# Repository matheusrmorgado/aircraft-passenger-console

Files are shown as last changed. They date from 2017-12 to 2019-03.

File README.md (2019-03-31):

# Controles Acessíveis em Aeronaves

## Projeto

Projeto desenvolvido em parceria com o [InovaLab@Poli](https://www.facebook.com/INOVALAB.POLI) e o [Centro Interdisciplinar de Tecnologias Interativas (CITI-USP)](http://www.lsi.usp.br/citi/).

O relatório completo do trabalho está disponível em [final-report.pdf](https://github.com/matheusrmorgado/aircraft-passenger-console/blob/master/final-report.pdf).

Uma apresentação resumida do projeto e dos resultados está disponível em [poster-presentation.pdf](https://github.com/matheusrmorgado/aircraft-passenger-console/blob/master/poster-presentation.pdf).

<p align="center">
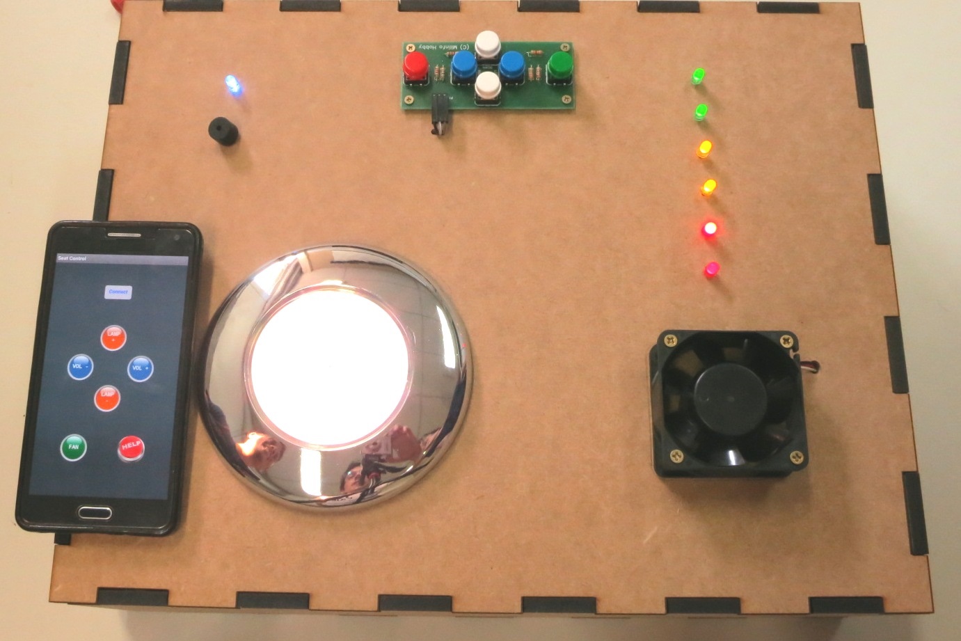
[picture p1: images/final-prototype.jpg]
  
</p>
<p align="center">
  <i> Youtube Video - https://youtu.be/7tW5oUx-QU8</i>
</p>

## Apresentação em Eventos

### Campus Mobile 2016 (Air Assistant)

> https://www.institutonetclaroembratel.org.br/educacao/nossas-novidades/noticias/jovens-empreendedores-se-reunem-na-etapa-presencial-do-programa-campus-mobile/

### IEEE ISCE 2016 (Enabling Technologies)

> http://isce2016.org.br/#overview_and_technical_program 

### TOM 2016  (Projetos 2016 - Slide 29)

> http://tom-sp.sedpcd.sp.gov.br/img/TOM.pdf

## Participação em Reportagens

### Movimento Maker - Estadão

> http://infograficos.estadao.com.br/e/focas/movimento-maker/tem-maker-na-medicina.php

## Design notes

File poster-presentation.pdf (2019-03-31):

# Accessible aircraft seat and console controls for passengers with disabilities through mobile devices

Matheus R. MORGADO, Marcelo A. JOSÉ, Member, IEEE, Alexandre M. ROCHA, André L. FLEURY,

Roseli D. LOPES, Member, IEEE, Eduardo S. ZANCUL Escola Politécnica
Universidade de São Paulo, São Paulo, Brazil matheus.morgado@usp.br, marcelo.archanjo@usp.br, arocha@usp.br, alfleury@usp.br, roseli.lopes@usp.br, ezancul@usp.br

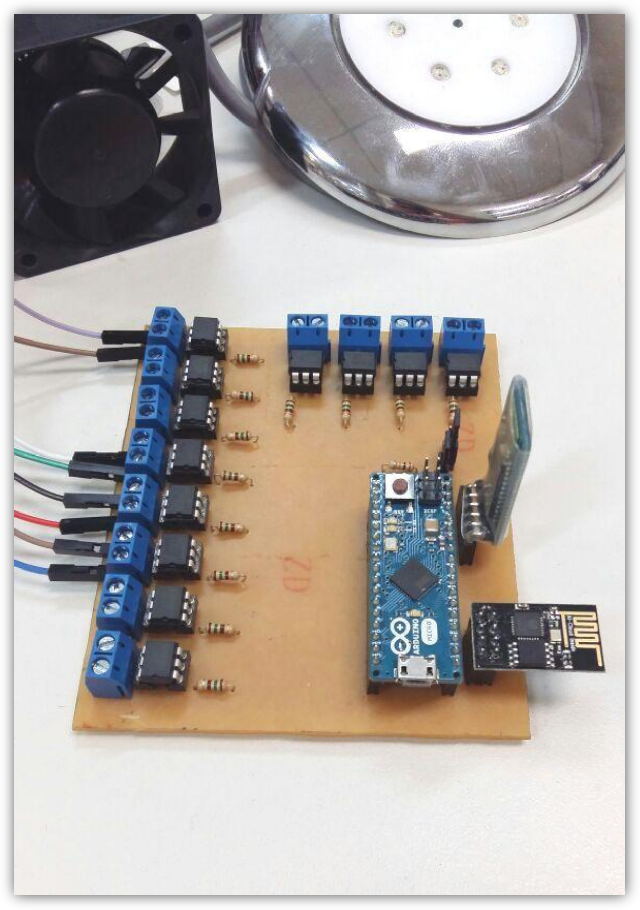
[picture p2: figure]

II. METHODS

This project is part of a larger project focused in the development of assistive technologies for improving the flight experience for people with disabilities or reduced mobility.

The project follows a methodological approach based on design thinking. The design thinking approach includes an initial project stage focused in the user understanding, followed by successive ideation and prototyping cycles.

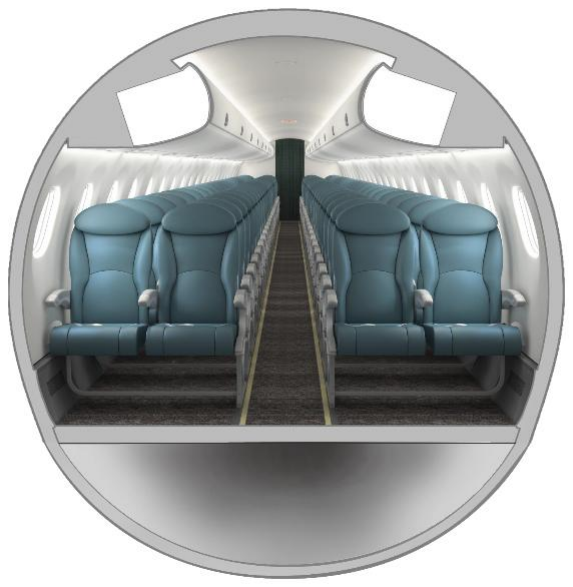
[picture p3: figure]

III. DEVELOPMENT

I. INTRODUCTION

People with disabilities usually face difficulties during travel in aircrafts. Among these difficulties, there are limitations while seated during the journey. The seat and console controls may be hard to reach and use or not accessible at all.

Considering the trend of airliners to allow the usage of wireless devices during flights, personal mobile devices become an option for improving comfort and creating a better experience for passengers with disabilities.

IV. RESULTS

The switches of the IFE controls, reading light and flight attendant call button of the aircraft represented in the final prototype were placed in parallel with solid state relays controlled by the Arduino.

The Arduino connects to a mobile device using Bluetooth or Wi-Fi and is controlled by a mobile application developed for this purpose.

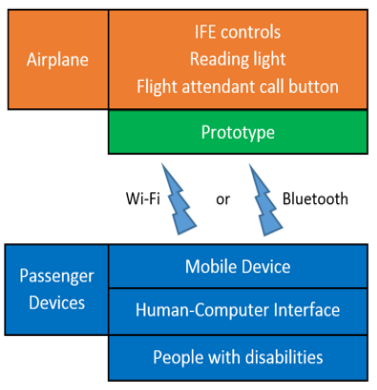
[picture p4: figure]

Fig. 1 Prototype architecture

Fig. 2 Functional prototype

The project includes a conceptual prototype that allows for a passenger with disabilities to make use of the IFE controls, the seat controls and the controls of the console above the seat using his own mobile devices.

- IFE controls
- on/off
- channel up
- channel down
- volume up
- volume down
- menu, select, back
- Reading light
- Flight attendant call button
- Two extra functions

The prototype provides twelve basic electronic functionalities, chosen after examining the most recent aircraft in-flight systems and understanding the user experience during the flight.

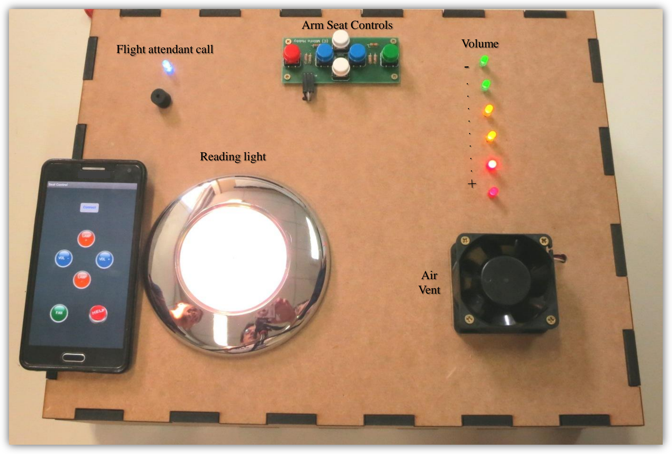
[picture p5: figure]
Flight attendant call; Reading light; Volume; Air Vent; Arm Seat Controls

V. CONCLUSIONS

The solution designed in this project is focused on the users’ requirements, specifically for those passengers with disabilities.

For people with disabilities, it means enabling their accessibility through the connectivity of their own personalized solution to the existing aircraft controls.

The functional prototype was built using solid state relays, an Arduino Micro, a HC-05 Bluetooth module and an ESP8266 for Wi-Fi communication.

ACKNOWLEDGEMENTS

Fig. 3 Final prototype

## The 20th IEEE International Symposium on Consumer Electronics

### ISCE

2016

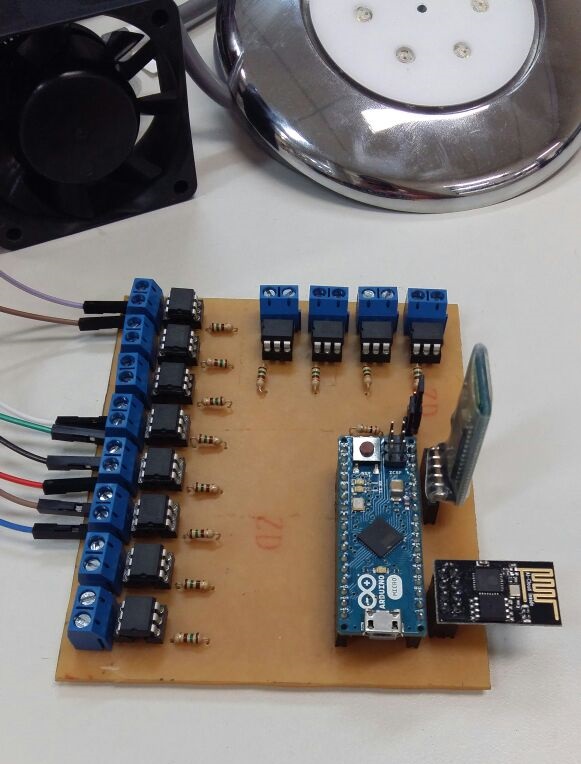
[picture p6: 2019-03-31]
images/electronic-circuit.jpg

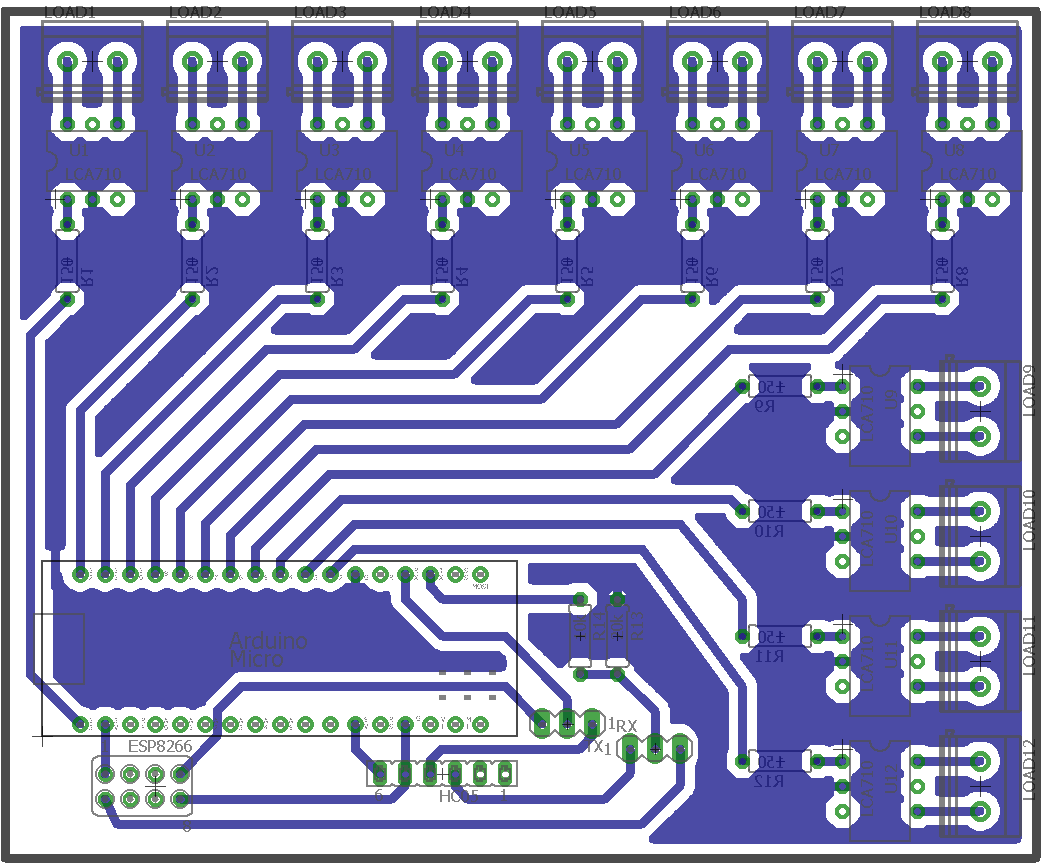
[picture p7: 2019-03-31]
schematic/Board.png

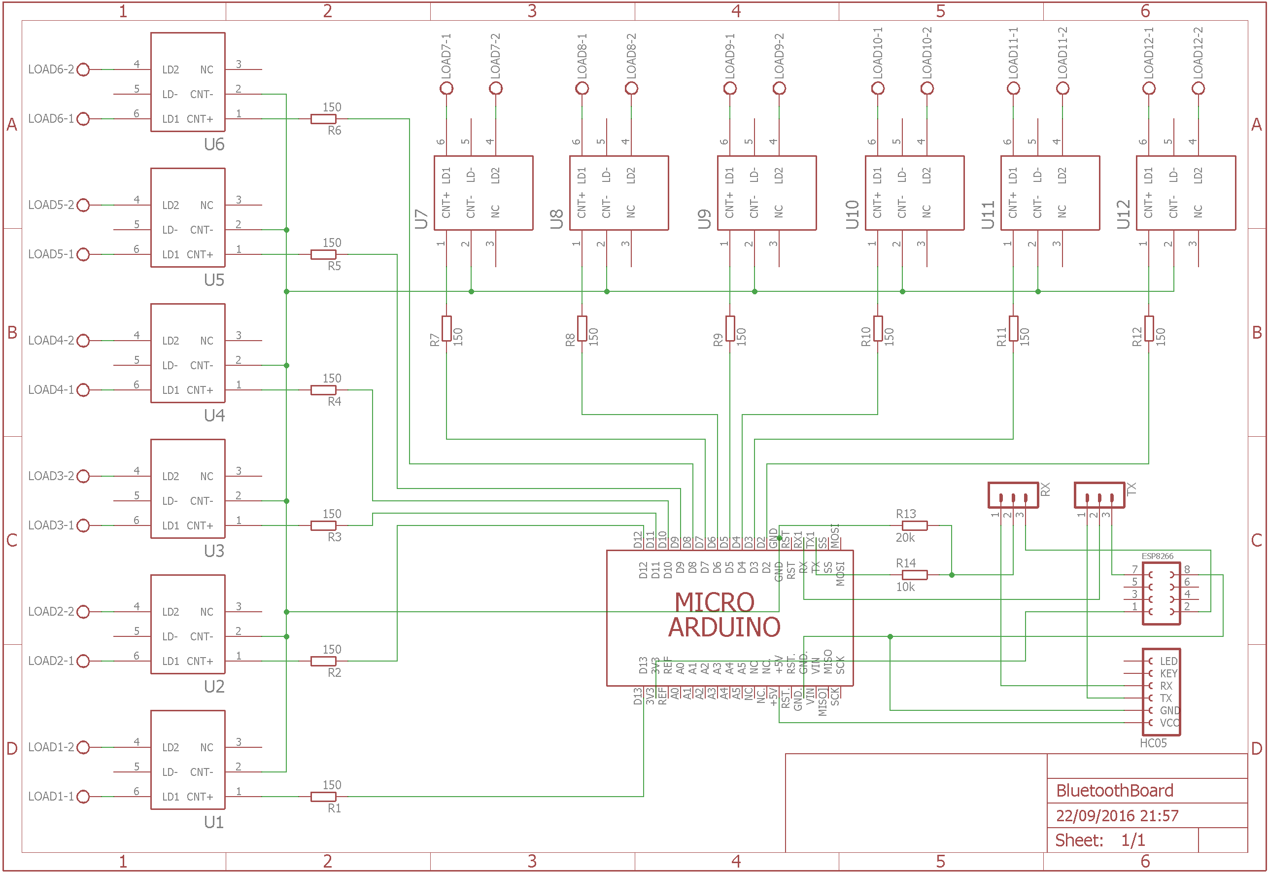
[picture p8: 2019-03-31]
schematic/Schematic.png

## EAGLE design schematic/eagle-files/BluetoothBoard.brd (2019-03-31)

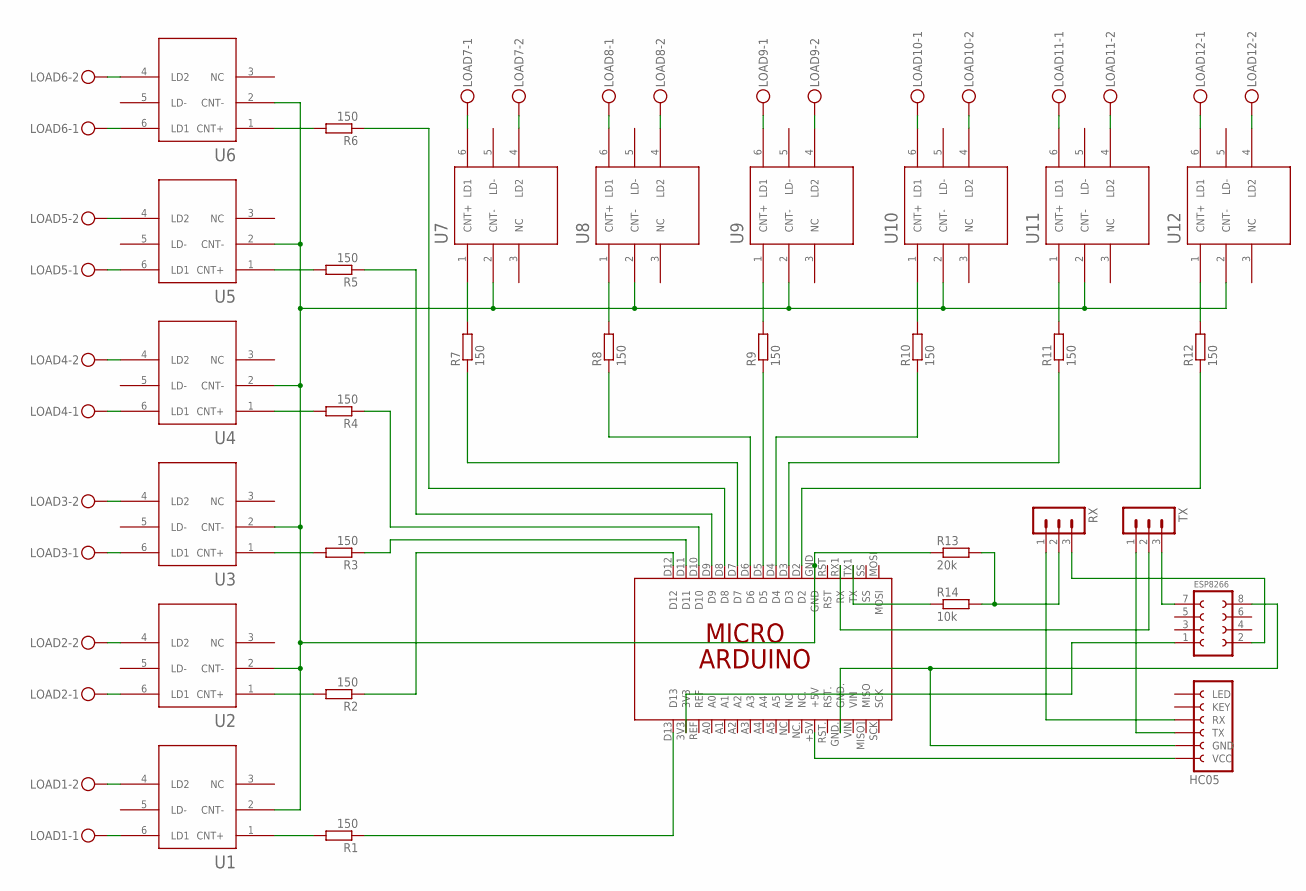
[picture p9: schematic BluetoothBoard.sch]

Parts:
ESP8266: ESP8266
HC05: FE06-1; FE06
LOAD1, LOAD2, LOAD3, LOAD4, LOAD5, LOAD6, LOAD7, LOAD8, LOAD9, LOAD10, LOAD11, LOAD12: MKDSN1,5/2-5,08
R1, R2, R3, R4, R5, R6, R7, R8, R9, R10, R11, R12: 150; 0207/7
R13: 20k; 0207/7
R14: 10k; 0207/7
RX: MA03-1
TX: MA03-1
U1, U2, U3, U4, U5, U6, U7, U8, U9, U10, U11, U12: LCA710; DIL-06
UC: ARDUINO_MICRO

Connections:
GND: R13.1, U1.2 (CNT-), U2.2 (CNT-), U3.2 (CNT-), U4.2 (CNT-), U5.2 (CNT-), U6.2 (CNT-), U7.2 (CNT-), U8.2 (CNT-), U9.2 (CNT-), U10.2 (CNT-), U11.2 (CNT-), U12.2 (CNT-), UC.GND
unnamed: R1.2, U1.1 (CNT+)
unnamed: LOAD1.2, U1.4 (LD2)
unnamed: LOAD1.1, U1.6 (LD1)
unnamed: R2.2, U2.1 (CNT+)
unnamed: LOAD2.1, U2.6 (LD1)
unnamed: LOAD2.2, U2.4 (LD2)
unnamed: R3.2, U3.1 (CNT+)
unnamed: LOAD3.1, U3.6 (LD1)
unnamed: LOAD3.2, U3.4 (LD2)
unnamed: R4.2, U4.1 (CNT+)
unnamed: LOAD4.1, U4.6 (LD1)
unnamed: LOAD4.2, U4.4 (LD2)
unnamed: R5.2, U5.1 (CNT+)
unnamed: LOAD5.1, U5.6 (LD1)
unnamed: LOAD5.2, U5.4 (LD2)
unnamed: R6.2, U6.1 (CNT+)
unnamed: LOAD6.1, U6.6 (LD1)
unnamed: LOAD6.2, U6.4 (LD2)
unnamed: TX.2, UC.RX1 (RX)
unnamed: ESP8266.1, UC.3V3
unnamed: R14.1, UC.TX1 (TX)
unnamed: ESP8266.2, RX.3
unnamed: R7.2, U7.1 (CNT+)
unnamed: LOAD7.1, U7.6 (LD1)
unnamed: LOAD7.2, U7.4 (LD2)
unnamed: R13.2, R14.2, RX.2
unnamed: R8.2, U8.1 (CNT+)
unnamed: LOAD8.1, U8.6 (LD1)
unnamed: HC05.6 (VCC), UC.+5V
unnamed: HC05.3 (RX), RX.1
unnamed: LOAD8.2, U8.4 (LD2)
unnamed: ESP8266.7 (TX), TX.3
unnamed: HC05.4 (TX), TX.1
unnamed: R9.2, U9.1 (CNT+)
unnamed: LOAD9.1, U9.6 (LD1)
unnamed: LOAD9.2, U9.4 (LD2)
unnamed: R10.2, U10.1 (CNT+)
unnamed: LOAD10.1, U10.6 (LD1)
unnamed: LOAD10.2, U10.4 (LD2)
unnamed: R11.2, U11.1 (CNT+)
unnamed: LOAD11.1, U11.6 (LD1)
unnamed: LOAD11.2, U11.4 (LD2)
unnamed: R12.2, U12.1 (CNT+)
unnamed: LOAD12.1, U12.6 (LD1)
unnamed: LOAD12.2, U12.4 (LD2)
unnamed: ESP8266.8, HC05.5 (GND), UC.GND.
unnamed: R12.1, UC.D2
unnamed: R11.1, UC.D3
unnamed: R10.1, UC.D4
unnamed: R9.1, UC.D5
unnamed: R8.1, UC.D6
unnamed: R7.1, UC.D7
unnamed: R6.1, UC.D8
unnamed: R5.1, UC.D9
unnamed: R4.1, UC.D10
unnamed: R3.1, UC.D11
unnamed: R1.1, UC.D13
unnamed: R2.1, UC.D12

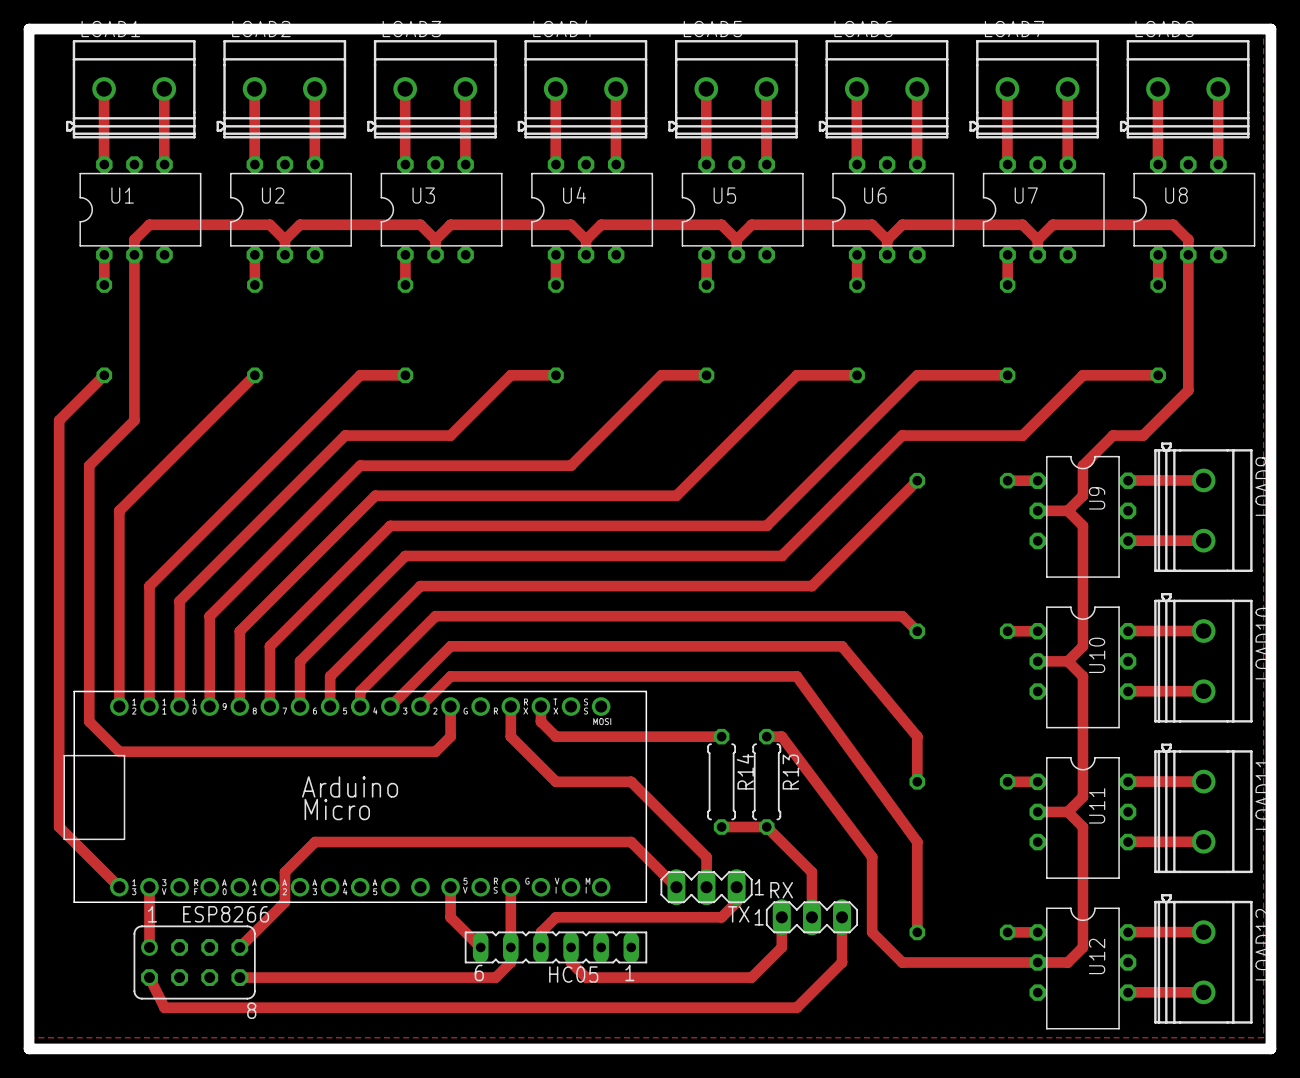
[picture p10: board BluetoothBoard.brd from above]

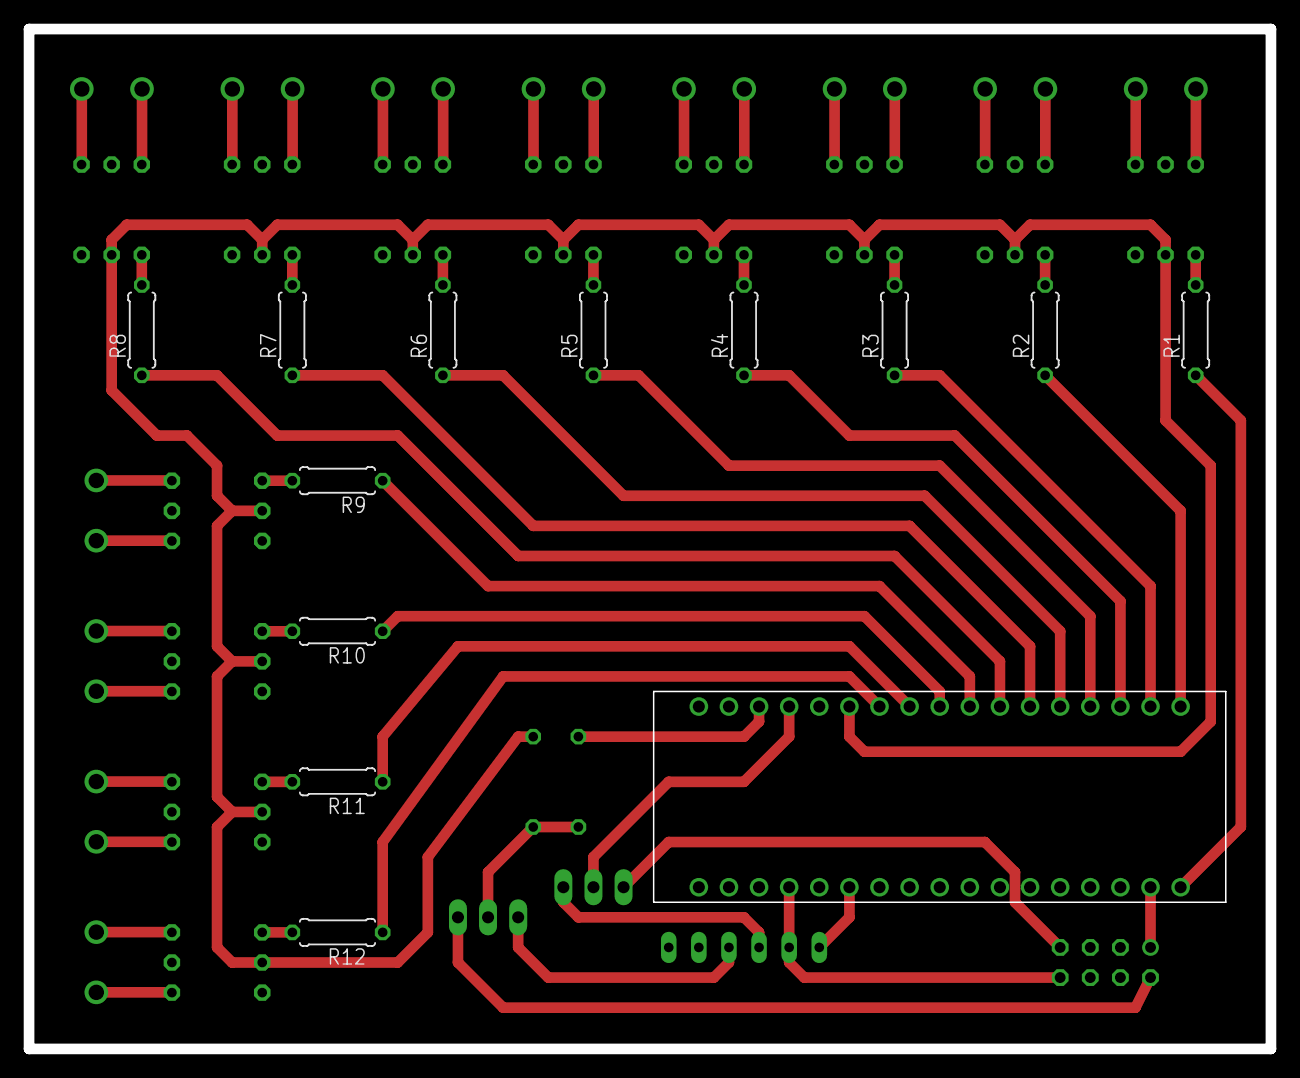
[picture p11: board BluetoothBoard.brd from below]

Board: 2 copper layers, 104.8 x 86.0 mm, 43 parts (12 on the bottom side), 59 nets.

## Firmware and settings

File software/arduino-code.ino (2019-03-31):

#include <Timer.h>

Timer t;

String comando = "";
int brilho = 0;
int leds = 0;

//Define estados iniciais
boolean status7 = false;
boolean status8 = false;

//Define os leds
int ledR = 9;
int ledG = 10;
int ledB = 11;
int cooler = 6;

int ledH = 2;
int buzzer = 3;

int led1 = 4;
int led2 = 5;
int led3 = 7;
int led4 = 8;
int led5 = 12;
int led6 = 13;

void setup()
{
  //Inicia a serial
  Serial.begin(115200);
  Serial1.begin(38400);

  //Inicia os leds desligados
  pinMode(ledR, OUTPUT);
  pinMode(ledG, OUTPUT);
  pinMode(ledB, OUTPUT);
  pinMode(cooler, OUTPUT);

  pinMode(ledH, OUTPUT);
  pinMode(buzzer, OUTPUT);

  pinMode(led1, OUTPUT);
  pinMode(led2, OUTPUT);
  pinMode(led3, OUTPUT);
  pinMode(led4, OUTPUT);
  pinMode(led5, OUTPUT);
  pinMode(led6, OUTPUT);

  digitalWrite(ledR, LOW);
  digitalWrite(ledG, LOW);
  digitalWrite(ledB, LOW);
  digitalWrite(cooler, LOW);

  digitalWrite(ledH, LOW);
  digitalWrite(buzzer, LOW);

  digitalWrite(led1, LOW);
  digitalWrite(led2, LOW);
  digitalWrite(led3, LOW);
  digitalWrite(led4, LOW);
  digitalWrite(led5, LOW);
  digitalWrite(led6, LOW);

  t.oscillate(ledH, 250, LOW);

}

void loop()
{

// Controle por App

  if (Serial1.available())
  {
    while (Serial1.available())
    {
      comando += (char)Serial1.read();
      delay(1);
    }

    Serial.println(comando);

    if (comando == "red") {
      if (brilho >= 40) {
        brilho -= 40;
        analogWrite(ledR, brilho);
        analogWrite(ledG, brilho);
        analogWrite(ledB, brilho);
      }
    }

    if (comando == "ylw") {
      if (brilho < 160) {
        brilho += 40;
        analogWrite(ledR, brilho);
        analogWrite(ledG, brilho);
        analogWrite(ledB, brilho);
      }
    }

    if (comando == "grn") {
      if (leds > 0) {
        if (leds == 6) {
          digitalWrite(led6, LOW);
        }
        if (leds == 5) {
          digitalWrite(led5, LOW);
        }
        if (leds == 4) {
          digitalWrite(led4, LOW);
        }
        if (leds == 3) {
          digitalWrite(led3, LOW);
        }
        if (leds == 2) {
          digitalWrite(led2, LOW);
        }
        if (leds == 1) {
          digitalWrite(led1, LOW);
        }
        leds -= 1;
      }
    }

    if (comando == "blu") {
      if (leds < 6) {
        if (leds == 5) {
          digitalWrite(led6, HIGH);
        }
        if (leds == 4) {
          digitalWrite(led5, HIGH);
        }
        if (leds == 3) {
          digitalWrite(led4, HIGH);
        }
        if (leds == 2) {
          digitalWrite(led3, HIGH);
        }
        if (leds == 1) {
          digitalWrite(led2, HIGH);
        }
        if (leds == 0) {
          digitalWrite(led1, HIGH);
        }
        leds += 1;
      }
    }

    if (comando == "fan") {
      if (status7) {
        digitalWrite(cooler, LOW);
        status7 = false;
      } else {
        analogWrite(cooler, 125);
        status7 = true;
      }
    }

    if (comando == "hlp") {
      if (status8) {
        digitalWrite(ledH, LOW);
        status8 = false;
      } else {
        digitalWrite(ledH, HIGH);

        tone(buzzer, 2000);
        delay(150);
        tone(buzzer, 2500);
        delay(200);
        tone(buzzer, 2000);
        delay(150);
        noTone(buzzer);

        status8 = true;
      }
    }

    comando = "";

  }

// Controle por botões

  int btnPress = analogRead(0);

  if (btnPress > 0) {
    //Serial.print ( "Botao pressionado: ");
    //Serial.print ( btnPress );

    if (btnPress < 100) {
      //Serial.println (" - ");
    }

    else if (btnPress < 200) {
      Serial.println (" - OK");
      if (status7) {
        digitalWrite(cooler, LOW);
        status7 = false;
      } else {
        analogWrite(cooler, 125);
        status7 = true;
      }
      delay(500);
    }

    else if (btnPress < 400) {
      Serial.println (" - DOWN");
      if (brilho >= 40) {
        brilho -= 40;
        analogWrite(ledR, brilho);
        analogWrite(ledG, brilho);
        analogWrite(ledB, brilho);
      }
      delay(500);
    }

    else if (btnPress < 600) {
      Serial.println (" - RIGHT");
      delay(500);
    }

    else if (btnPress < 750) {
      Serial.println (" - UP");
      if (brilho < 160) {
        brilho += 40;
        analogWrite(ledR, brilho);
        analogWrite(ledG, brilho);
        analogWrite(ledB, brilho);
      }
      delay(500);
    }

    else if (btnPress < 900) {
      Serial.println (" - LEFT");
      delay(500);
    }

    else if (btnPress > 1000) {
      Serial.println (" - CANCEL");
      if (status8) {
        digitalWrite(ledH, LOW);
        status8 = false;
        delay(500);
      } else {
        digitalWrite(ledH, HIGH);

        tone(buzzer, 2000);
        delay(150);
        tone(buzzer, 2500);
        delay(200);
        tone(buzzer, 2000);
        delay(150);
        noTone(buzzer);

        status8 = true;
      }
    }

  }

  if (status8) {
    t.update();
  }

}

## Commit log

2019-03-31 Update schematic files
    [BluetoothBoard.brd, BluetoothBoard.sch]
2019-03-31 Update project documentation
    [BluetoothBoard.brd, BluetoothBoard.sch]
